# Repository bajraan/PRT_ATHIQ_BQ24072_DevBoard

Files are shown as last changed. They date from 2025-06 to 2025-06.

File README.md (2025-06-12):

<!-- Begin README -->

<div align="center">
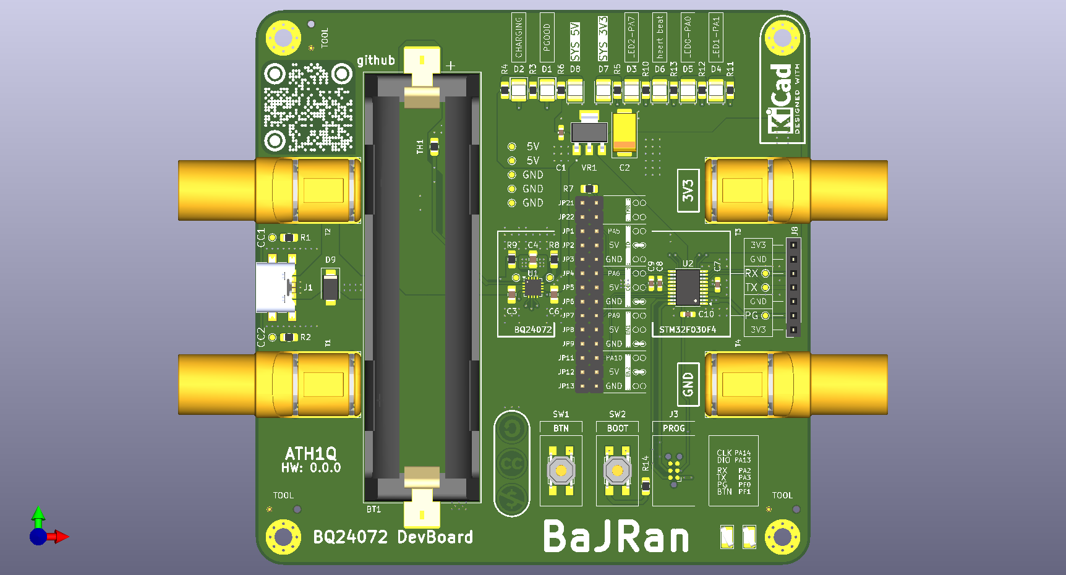
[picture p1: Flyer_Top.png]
    
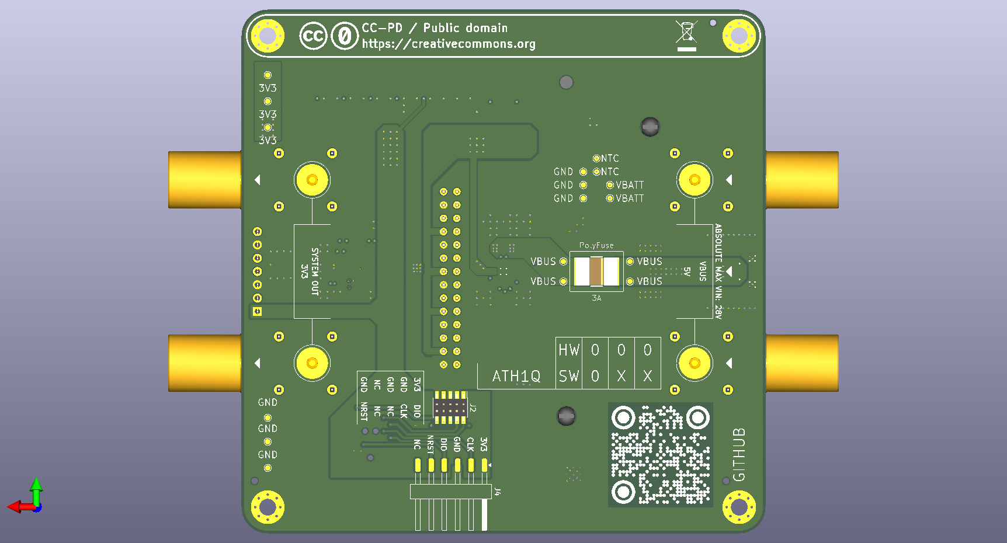
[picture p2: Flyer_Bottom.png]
    
</div>
f
<p align="center">
    
    
    
    <br>
</p>

> [!NOTE]
> TODO:

> [!NOTE]
> **SW:**
<a href="https://www.kicad.org/">
    
</a>
<br><br><br><br>

<div align="center">
    
</div>

<!-- VARIANTS SECTION -->
<!-- VARIANTS SECTION -->
<!-- VARIANTS SECTION -->

<!-- GALLERY SECTION -->
<!-- GALLERY SECTION -->
<!-- GALLERY SECTION -->

---

<div align="center">
    
    
</div>

<!-- End README -->
<!-- github background #0d1117 -->

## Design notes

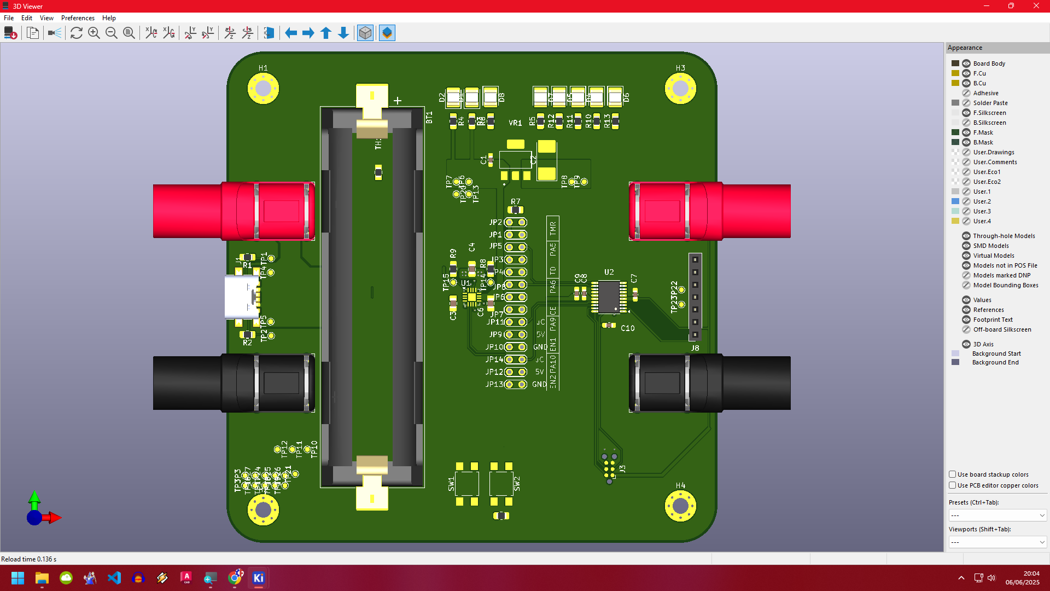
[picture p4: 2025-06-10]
21_Electrical/00__Screens_1/Screenshot (2026).png

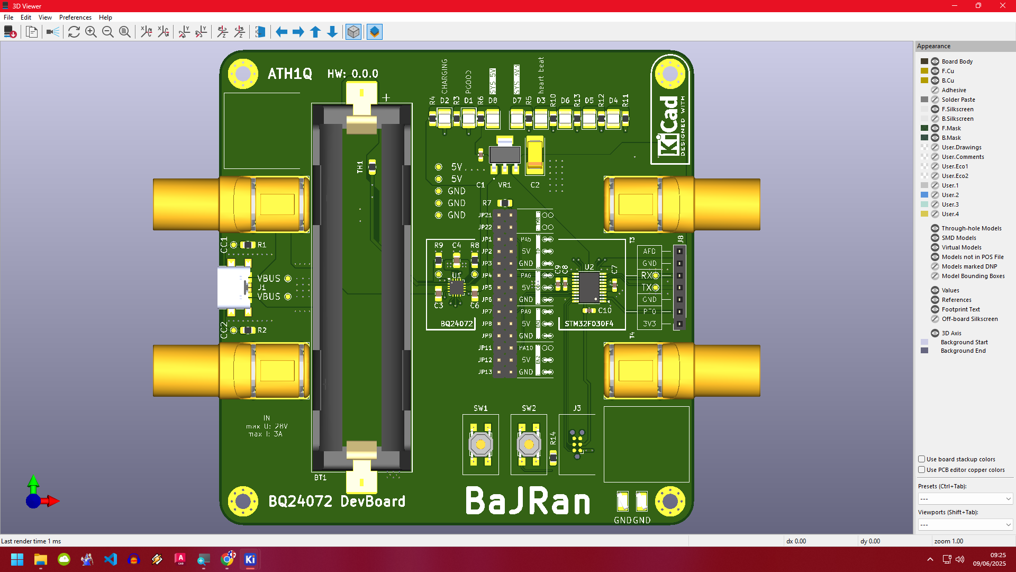
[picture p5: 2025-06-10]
21_Electrical/00__Screens_1/Screenshot (2047).png

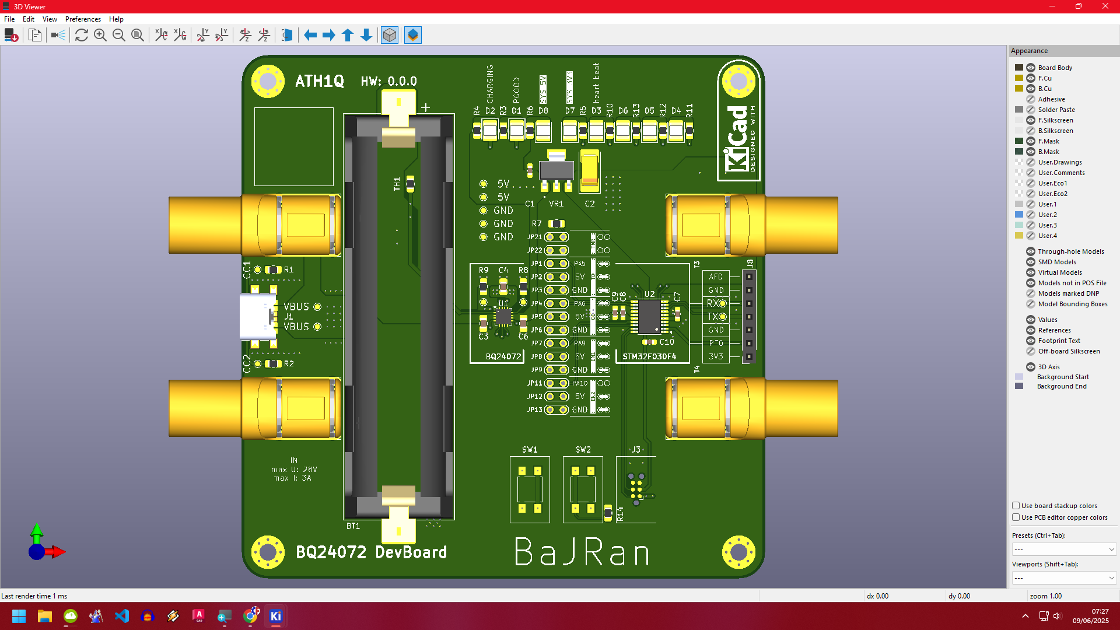
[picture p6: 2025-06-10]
21_Electrical/00__Screens_1/Screenshot (2044).png

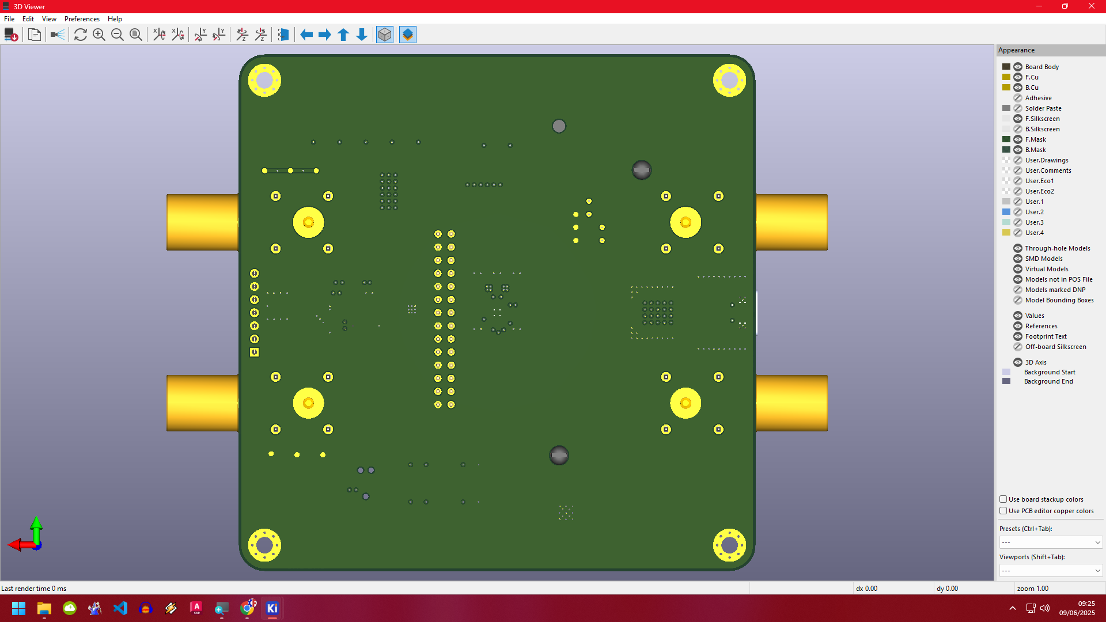
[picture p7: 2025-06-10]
21_Electrical/00__Screens_1/Screenshot (2048).png

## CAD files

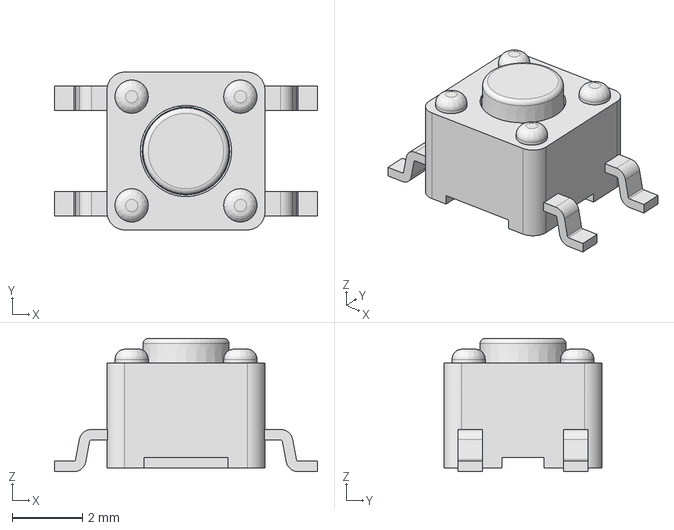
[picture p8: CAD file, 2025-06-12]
21_Electrical/__E-Switch_TL3305A/TL3305AF160QG.STEP
7.50 x 4.50 x 3.80 mm

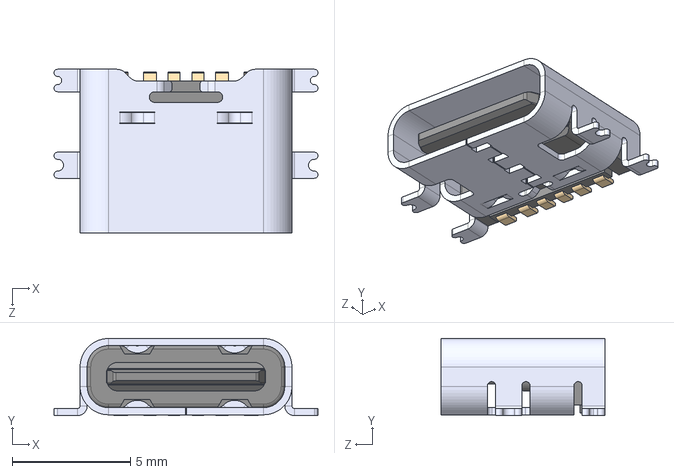
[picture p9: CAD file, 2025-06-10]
21_Electrical/__GCT_USB4135-GF-A/USB4135-GF-A.step
11.1 x 3.25 x 6.90 mm

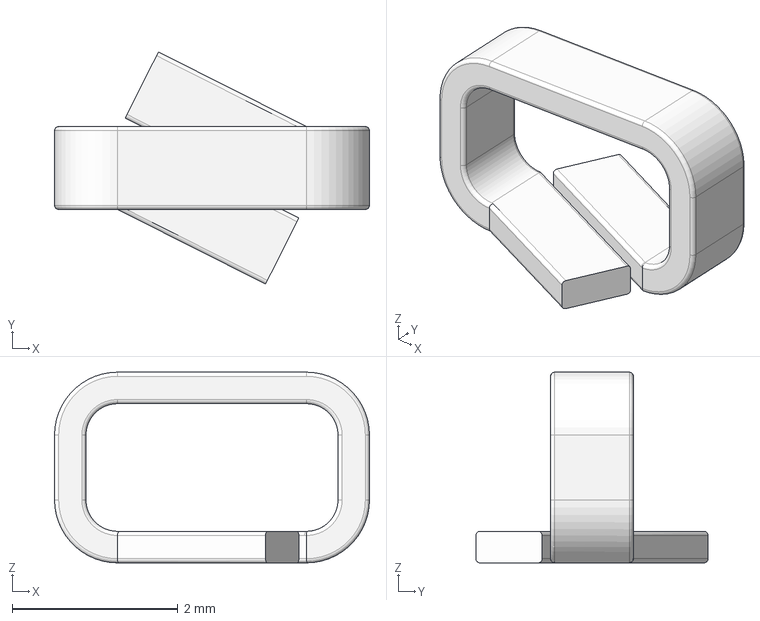
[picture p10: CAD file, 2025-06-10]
21_Electrical/__KEYSTONE_5016_TestPoint/KEYSTONE_5016.step
3.80 x 2.80 x 2.30 mm

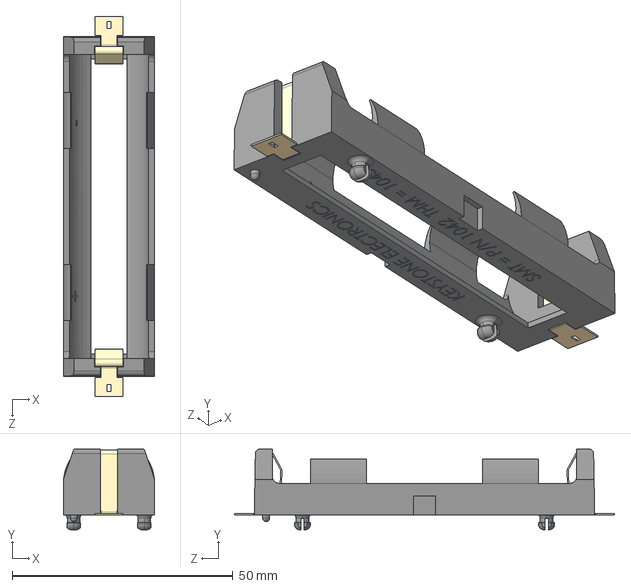
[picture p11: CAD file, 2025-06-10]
21_Electrical/__Keystone_PN1042/keystone-PN1042.STEP
20.7 x 18.3 x 86.0 mm

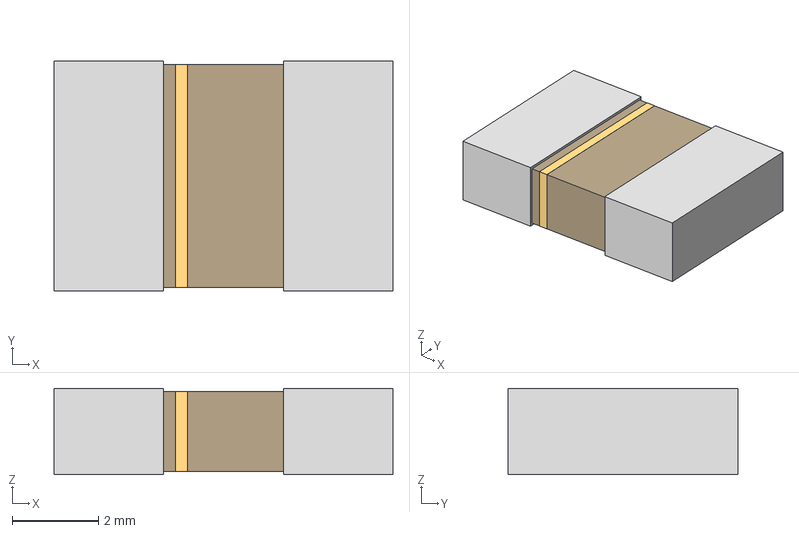
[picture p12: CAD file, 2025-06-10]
21_Electrical/__Littelfuse_2920L330/FUSE_2920L33024MR_LTF.step
7.87 x 5.33 x 2.01 mm

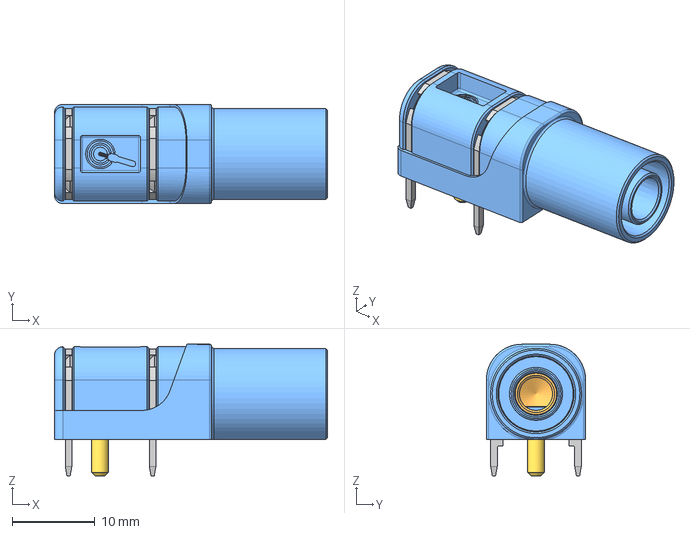
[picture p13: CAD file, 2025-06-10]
21_Electrical/__Schutzinger_SWEB_8094/SWEB_8094_AU_BL.step
33.0 x 12.0 x 15.9 mm

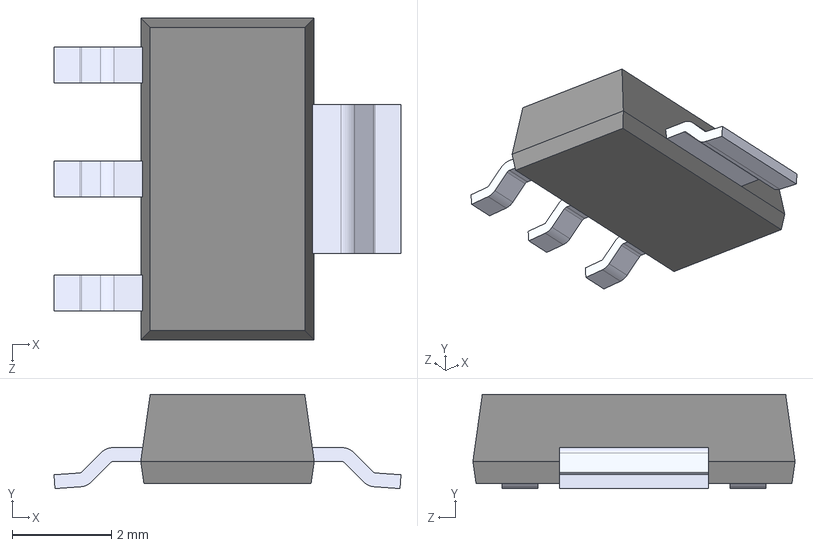
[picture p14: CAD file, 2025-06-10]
21_Electrical/__TAIWAN_SEMI__TS2940CW33_RPG/TS2940CW33_RPG.step
7.00 x 1.90 x 6.50 mm

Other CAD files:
21_Electrical/__Schutzinger_SWEB_8094/SWEB_8094_AU_OR.step
21_Electrical/__Schutzinger_SWEB_8094/SWEB_8094_AU_SW.step
21_Electrical/__Schutzinger_SWEB_8094/SWEB_8094_AU_GN.step
21_Electrical/__Schutzinger_SWEB_8094/SWEB_8094_AU_GE.step
21_Electrical/__Schutzinger_SWEB_8094/SWEB_8094_AU_RT.step

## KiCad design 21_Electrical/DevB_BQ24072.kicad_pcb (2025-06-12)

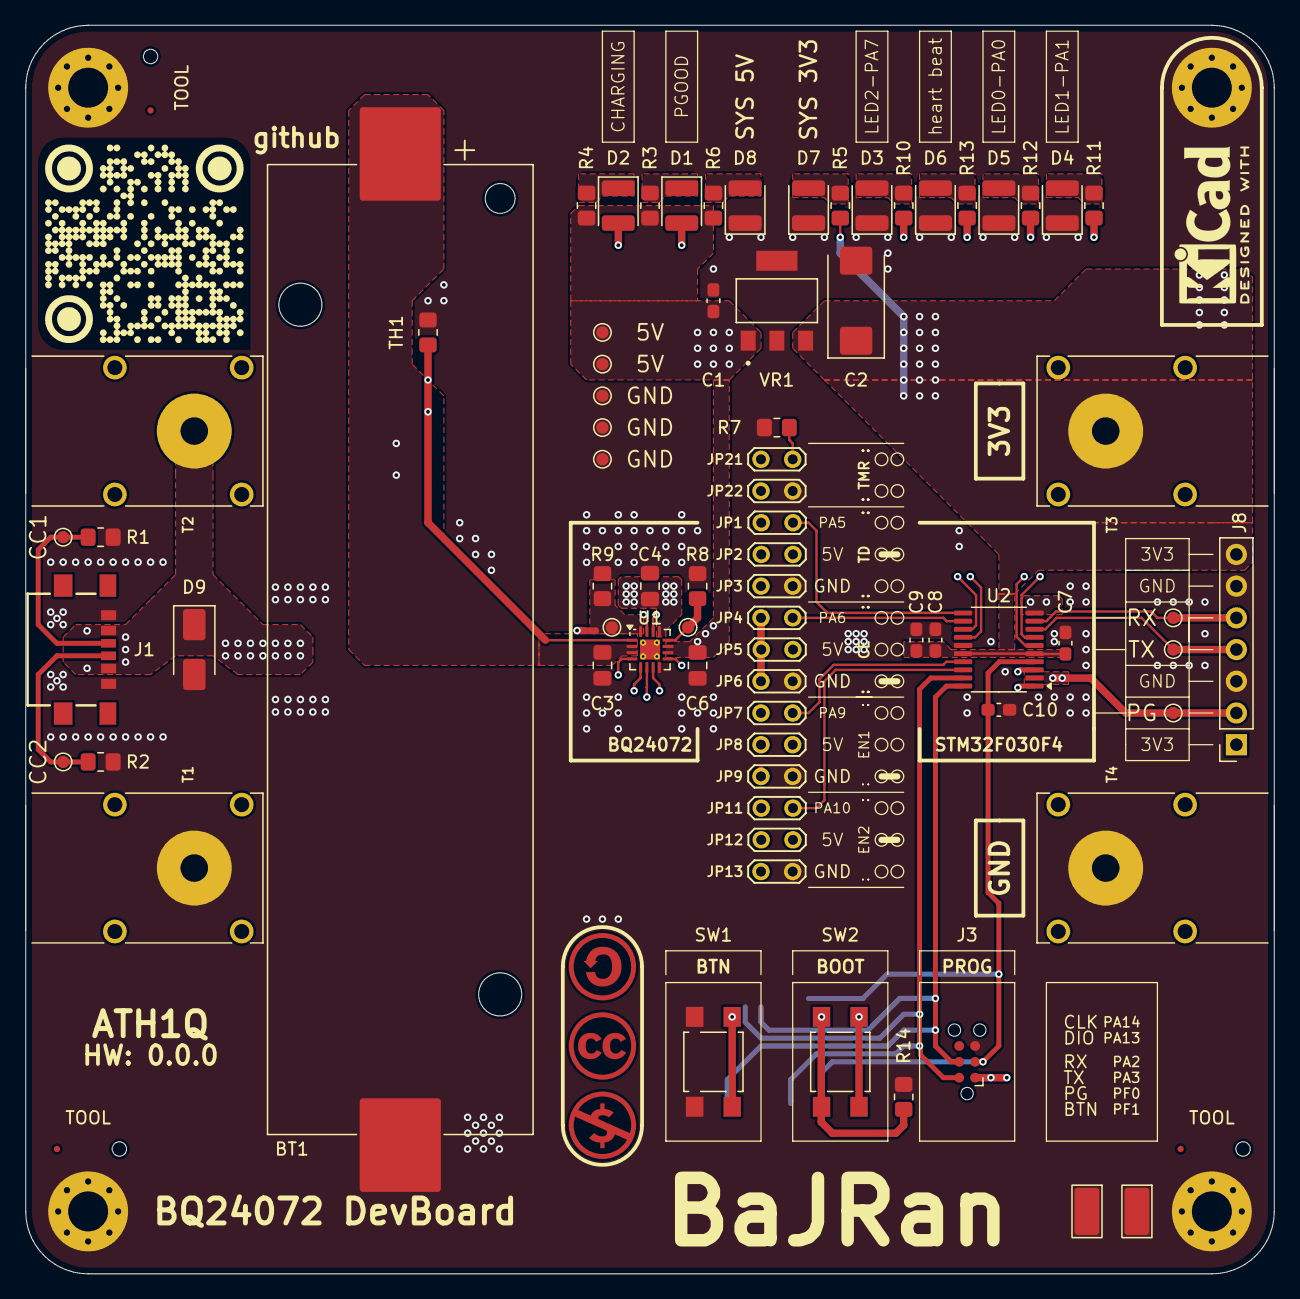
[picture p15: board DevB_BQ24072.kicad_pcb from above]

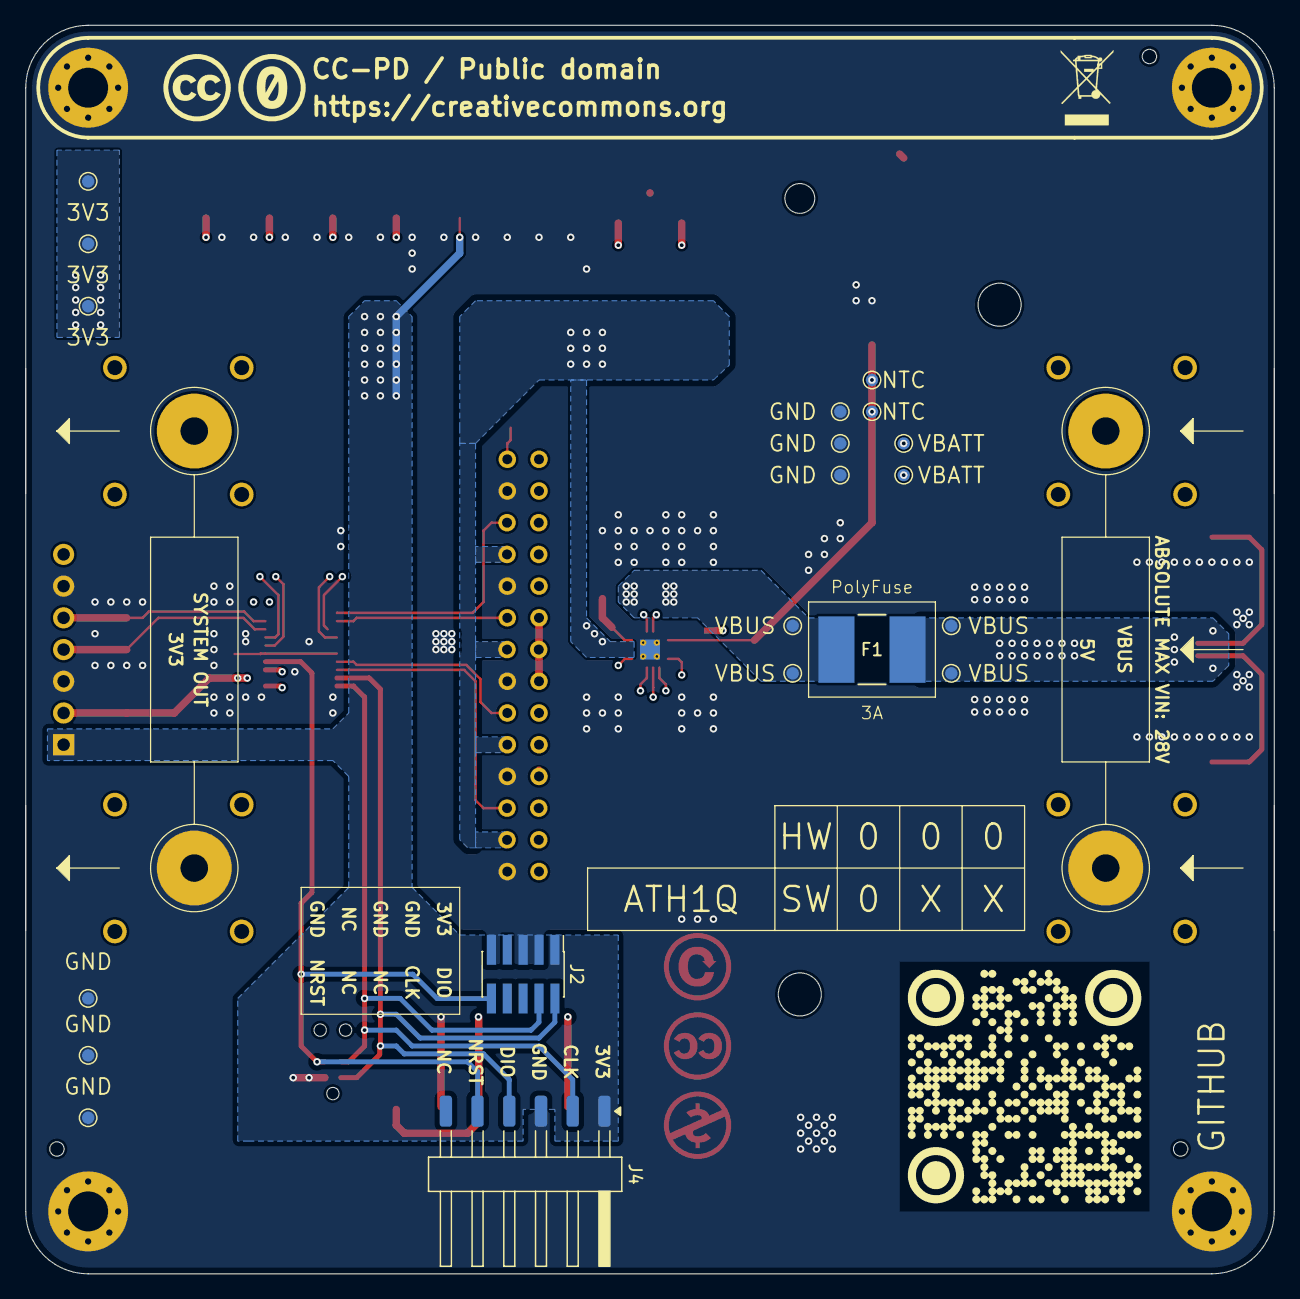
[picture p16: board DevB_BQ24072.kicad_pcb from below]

Board: 4 copper layers, 100.0 x 100.0 mm, 105 parts (20 on the bottom side), 43 nets.

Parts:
BT1: 18650; BatteryHolder_Keystone_1042_1x18650
C1, C9: 1u/50V; C_0603_1608Metric_Pad1.08x0.95mm_HandSolder
C2: 47u/16V; CP_EIA-7343-31_Kemet-D_HandSolder
C3, C4, C6: 4u7/35V; C_0805_2012Metric_Pad1.18x1.45mm_HandSolder
C7, C8, C10: 100n/50V; C_0603_1608Metric_Pad1.08x0.95mm_HandSolder
D1, D2, D3, D4, D5, D6, D7, D8: LED_Small_Filled; LED_1210_3225Metric
D9: SMAJ24A; D_SMA
F1: 2920L330/24MR; FUSE_2920L330_24MR_LTF
FID1, FID2, FID3: Fiducial; Fiducial_0.5mm_Mask1mm
H1, H2, H3, H4: MountingHole_Pad; MountingHole_3.2mm_M3_Pad_Via
H5, H6, H7: MountingHole_Pad; ToolingHole_1.152mm
J1: USB4135-GF-A_REVA; GCT_USB4135-GF-A_REVA
J2: Conn_ARM_JTAG_SWD_10; PinHeader_2x05_P1.27mm_Vertical_SMD
J3: SWD1; Tag-Connect_TC2030-IDC-NL_2x03_P1.27mm_Vertical
J4: Conn_01x06_Pin; Harwin_M20-89006xx_1x06_P2.54mm_Horizontal
J8: Conn_01x07_Pin; PinSocket_1x07_P2.54mm_Vertical
JP1, JP2, JP3, JP4, JP5, JP6, JP7, JP8, JP9, JP11, JP12, JP13, JP21, JP22: Jumper_2_Open; TestPoint_2Pads_Pitch2.54mm_Drill0.8mm
NT2: NetTie_2; NetTie-2_SMD_Pad0.5mm
R1, R2: 5k1; R_0805_2012Metric_Pad1.20x1.40mm_HandSolder
R3, R4, R10, R11, R12, R13: 1k; R_0805_2012Metric_Pad1.20x1.40mm_HandSolder
R5: 200; R_0805_2012Metric_Pad1.20x1.40mm_HandSolder
R6: 370; R_0805_2012Metric_Pad1.20x1.40mm_HandSolder
R7: XX; R_0805_2012Metric_Pad1.20x1.40mm_HandSolder
R8: 1k15; R_0805_2012Metric_Pad1.20x1.40mm_HandSolder
R9: 0k65; R_0805_2012Metric_Pad1.20x1.40mm_HandSolder
R14: 10k; R_0805_2012Metric_Pad1.20x1.40mm_HandSolder
SW1: BTN; SW_SPST_TL3305A
SW2: BOOT0; SW_SPST_TL3305A
T1, T2, T3, T4: SWEB_8094; SWEB_8094_GE
TH1: 10k; R_0805_2012Metric_Pad1.20x1.40mm_HandSolder
TP1: CC1; TestPoint_Pad_D1.0mm
TP2: CC2; TestPoint_Pad_D1.0mm
TP3, TP11, TP12, TP13, TP20, TP24, TP25, TP26, TP27: GND; TestPoint_Pad_D1.0mm
TP4, TP5, TP28, TP29: VBUS; TestPoint_Pad_D1.0mm
TP6, TP7: 5V; TestPoint_Pad_D1.0mm
TP8, TP9, TP10: 3V3; TestPoint_Pad_D1.0mm
TP14: ilim; TestPoint_Pad_D1.0mm
TP15: iset; TestPoint_Pad_D1.0mm
TP16, TP17: VBATT; TestPoint_Pad_D1.0mm
TP18, TP19: NTC; TestPoint_Pad_D1.0mm
TP21: PG; TestPoint_Pad_D1.0mm
TP22: RX; TestPoint_Pad_D1.0mm
TP23: TX; TestPoint_Pad_D1.0mm
TP31: GND; TestPoint_Keystone_5019_Miniature
TP32: TestPoint; TestPoint_Keystone_5019_Miniature
U1: BQ24072RGT; VQFN-16-1EP_3x3mm_P0.5mm_EP1.6x1.6mm_ThermalVias
U2: STM32F030F4Px; TSSOP-20_4.4x6.5mm_P0.65mm
VR1: TS2940CW33_RPG

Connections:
/BAT_NTC: TH1.1, TP18.1, TP19.1, U1.1 (TS)
/BAT_V: BT1.1 (+), C3.1, TP16.1, TP17.1, U1.2 (BAT), U1.3 (BAT)
/BQ_ilim: R8.1, TP14.1, U1.12 (ILIM)
/BQ_iset: NT2.1, R9.1, TP15.1, U1.16 (ISET)
/BQ_tmr: JP21.1 (A), JP22.1 (A), U1.14 (TMR)
/BTN: SW1.2, U2.3 (PF1)
/BTN_boot: R14.1, SW2.2, U2.1 (BOOT0)
/CFG_CE: JP4.1 (A), JP5.1 (A), JP6.1 (A), U1.4 (~CE)
/CFG_EN1: JP7.1 (A), JP8.1 (A), JP9.1 (A), U1.6 (EN1)
/CFG_EN2: JP11.1 (A), JP12.1 (A), JP13.1 (A), U1.5 (EN2)
/CFG_TD: JP1.1 (A), JP2.1 (A), JP3.1 (A), U1.15 (TD)
/LED_0: R12.1, U2.6 (PA0)
/LED_1: R11.1, U2.7 (PA1)
/LED_2: R10.1, U2.13 (PA7)
/LED_3V3: D7.2 (A), R5.2
/LED_5V: D8.2 (A), R6.2
/LED_10: D5.2 (A), R12.2
/LED_11: D4.2 (A), R11.2
/LED_12: D3.2 (A), R10.2
/LED_PG: D2.2 (A), J8.2, TP21.1, U1.7 (~PGOOD), U2.2 (PF0)
/LED_PG1: D2.1 (K), R4.1
/LED_hG: D1.2 (A), U1.9 (~CHG)
/LED_hG1: D1.1 (K), R3.1
/LED_heartBeat: R13.1, U2.14 (PB1)
/PWR_SYS_3V3: C2.1, C7.1, C8.1, C9.1, J2.1 (VTref), J3.1 (VCC), J4.1, J8.1, J8.7, R5.1, SW2.1, T3.1, TP8.1, TP9.1, TP10.1, U2.5 (VDDA), U2.16 (VDD), VR1.3 (OUT)
/PWR_SYS_5V: C1.1, C6.1, JP2.2 (B), JP5.2 (B), JP8.2 (B), JP12.2 (B), R3.2, R4.2, R6.1, TP6.1, TP7.1, U1.10 (OUT), U1.11 (OUT), VR1.1 (IN)
/PWR_VBUS: D9.1 (A1), F1.1, J1.A9 (VBUS_A), J1.B9 (VBUS_B), T2.1, TP4.1, TP5.1
/PWR_VBUS_F: C4.1, F1.2, TP28.1, TP29.1, U1.13 (IN)
/STM_CE: JP4.2 (B), U2.12 (PA6)
/STM_EN1: JP7.2 (B), U2.17 (PA9)
/STM_EN2: JP11.2 (B), U2.18 (PA10)
/STM_TD: JP1.2 (B), U2.11 (PA5)
/STM_isense: NT2.2, U2.10 (PA4)
/SW_CLK: J2.4 (SWCLK/TCK), J3.4 (SWCLK), J4.2, U2.20 (PA14)
/SW_DIO: J2.2 (SWDIO/TMS), J3.2 (SWDIO), J4.4, U2.19 (PA13)
/SW_NRST: C10.1, J2.10 (~RESET), J3.3 (~RESET), J4.5, U2.4 (NRST)
/USART_RX: J8.5, TP22.1, U2.9 (PA3)
/USART_TX: J8.4, TP23.1, U2.8 (PA2)
/USB_CC1: J1.A5 (CC1), R1.1, TP1.1
/USB_CC2: J1.B5 (CC2), R2.1, TP2.1
GND: BT1.2 (-), C1.2, C2.2, C3.2, C4.2, C6.2, C7.2, C8.2, C9.2, C10.2, D3.1 (K), D4.1 (K), D5.1 (K), D6.1 (K), D7.1 (K), D8.1 (K), D9.2 (A2), H1.1, H2.1, H3.1, H4.1, J1.A12 (GND_A), J1.B12 (GND_B), J2.3 (GND), J2.5 (GND), J2.9 (GNDDetect), J3.5 (GND), J4.3, J8.3, J8.6, JP3.2 (B), JP6.2 (B), JP9.2 (B), JP13.2 (B), JP22.2 (B), R1.2, R2.2, R7.1, R8.2, R9.2, R14.2, SW1.1, T1.1, T4.1, TH1.2, TP3.1, TP11.1, TP12.1, TP13.1, TP20.1, TP24.1, TP25.1, TP26.1, TP27.1, TP31.1, TP32.1, U1.8 (VSS), U1.17 (VSS), U2.15 (VSS), VR1.2 (GND), VR1.4 (GND)
unnamed: D6.2 (A), R13.2
unnamed: JP21.2 (B), R7.2

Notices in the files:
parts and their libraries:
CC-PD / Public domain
